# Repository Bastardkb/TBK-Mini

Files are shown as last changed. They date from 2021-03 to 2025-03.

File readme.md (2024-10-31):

# TBK Mini

A Dactyl Manuform Mini. Silent and compact, with per-key RGB.

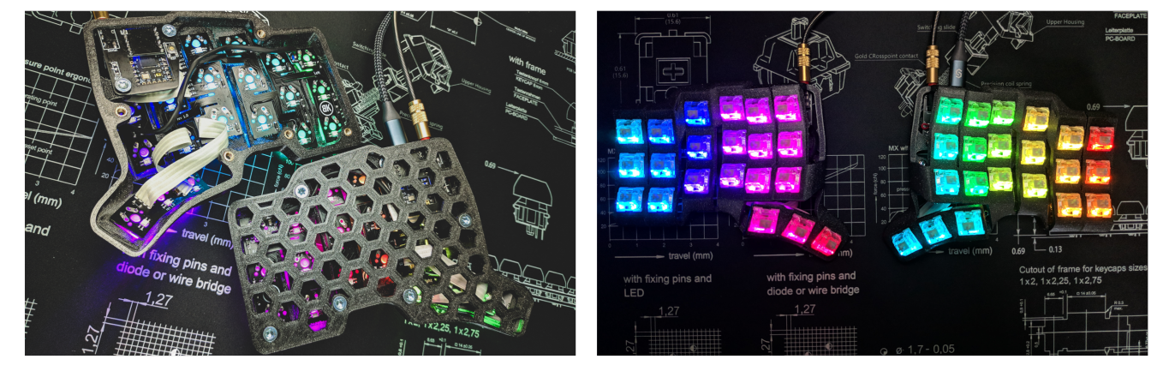
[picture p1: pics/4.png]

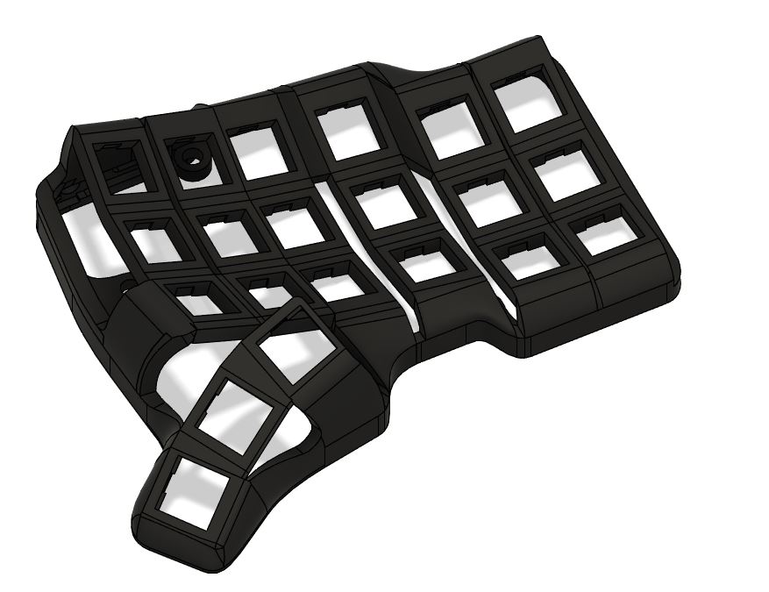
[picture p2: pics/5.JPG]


# Sourcing the components

## Electronic components

You will need to order the parts from a shop, and order some PCBs directly from the manufacturer.

Parts list:

| Part name | Amount | Link |
| --- | --- | --- |
| Flexible PCB for the plate | 2 | https://github.com/Bastardkb/TBK-Mini-PCB-plate |
| Flexible PCB for the thumbs | 2 | https://github.com/Bastardkb/TBK-Mini-PCB-thumb-cluster |
| Elite-C | 2 | |
| Elite-C adapter PCB V1.4 | 2 | https://github.com/Bastardkb/Elite-C-holder |
| SOD123 Diodes | 42 | |
| Ribbon cables Flexstrip | 34 | Farnell, Aliexpress |
| M4 8mm Torx Screw | 14 | Conrad |
| M4 screw insert, M4 X D6.0 X L5.0 | 14 | https://fr.aliexpress.com/item/4000232925592.html?spm=a2g0s.12269583.0.0.6aef4f282LZO4v |
| Audio jack, SMD | 2 | |
| Button, 4x4x1.5 | 2 | https://www.aliexpress.com/item/1005001304569553.html?spm=a2g0s.9042311.0.0.27424c4dDwgcp7 |

If you want RGB, you will also need:

| Part name | Amount | Format |
| --- | --- | --- |
| SK6812 Mini-E LEDs | 42 | |
| Capacitor, 1uF | 4 | 1206 |
| Resistor, 330Ohms | 4 | 1206 |
| Wires | | 28 AWG recommended, Black, Red, Color |
| Ribbon cables Flexstrip | 6 | |

## Print the case

The STL files are included in this Github repository.

Please find detailed instructions on how to print the case on the online instructions linked below.

There are optional tents, use the same ones as for the [Charybdis Mini 3x6](https://github.com/bastardkb/charybdis).

## Get a kit from BastardKB

You can also get a full Kit, including case and all PCBs and electronics required on the shop:
https://bastardkb.com/

If you want to print the case yourself, you can also get just the electronics Kit.

# Build guide

You can find detailed instruction on the online documentation linked below. For the TBK Mini, please follow the Skeletyl guide.

# Finding help

- Discord: https://bastardkb.com/discord
- Website: https://bastardkb.com/
- Docs: https://docs.bastardkb.com

# Forks

- [With loligagger holder for nice!nanos](https://github.com/nathanielks/TBK-Mini) - reset switch and power switch

# License

This work is licensed under a Creative Commons Attribution-NonCommercial-ShareAlike 4.0 International License.

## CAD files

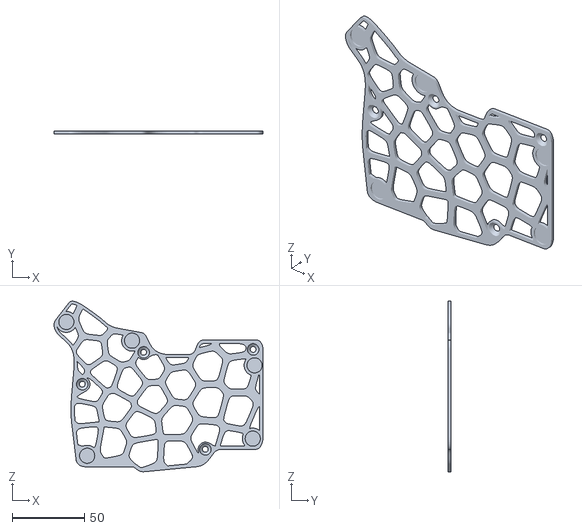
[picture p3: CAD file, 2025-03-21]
files/plate_flush_v1_v2.stl
144.4 x 2.00 x 117.9

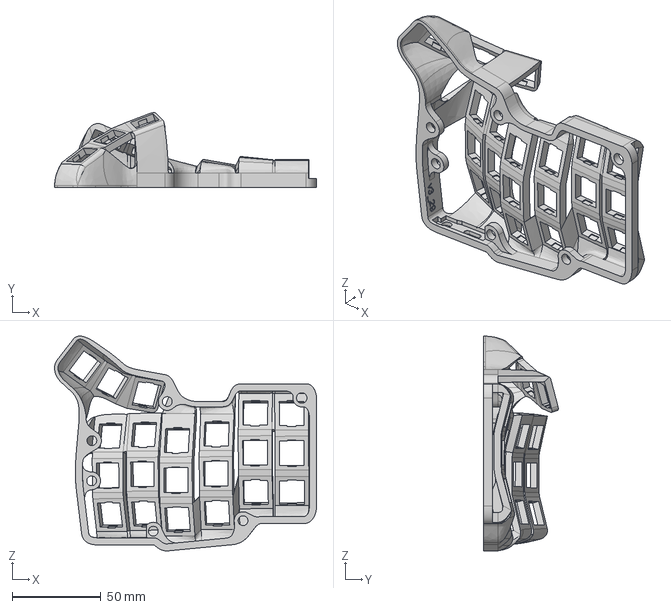
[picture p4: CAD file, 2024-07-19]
files/mini_v3 v29.step
147.4 x 42.0 x 120.9 mm

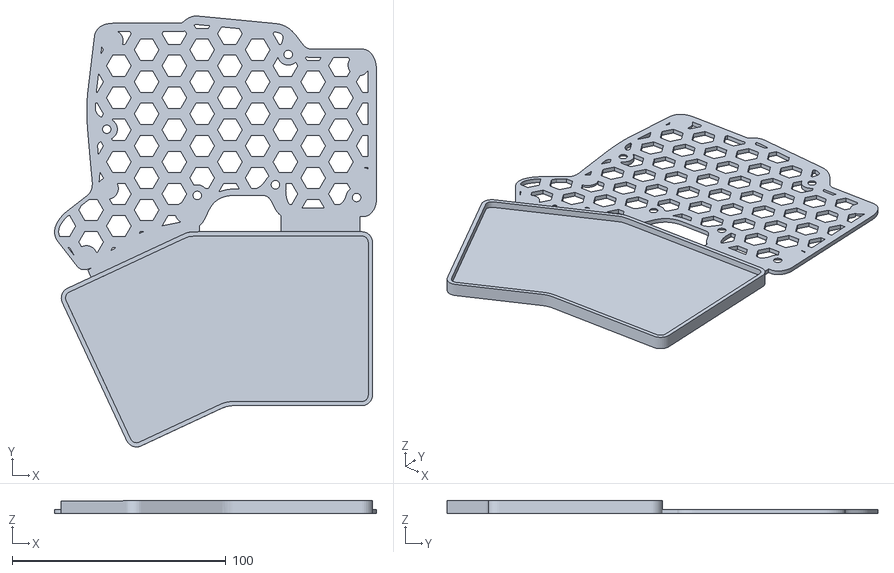
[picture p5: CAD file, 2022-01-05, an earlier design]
files/archive/plate_ergodox_ez_wing.stl
150.8 x 201.8 x 6.18

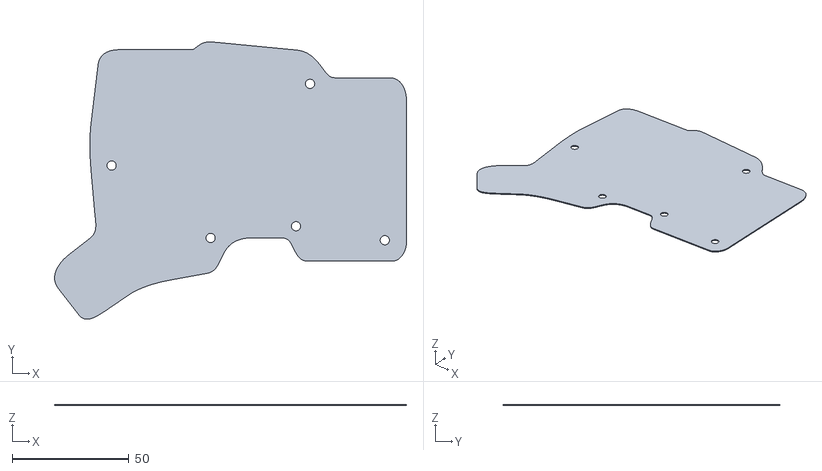
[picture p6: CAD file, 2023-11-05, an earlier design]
files/archive/tents/plate_protection_layer.stl
150.8 x 118.8 x 0.5

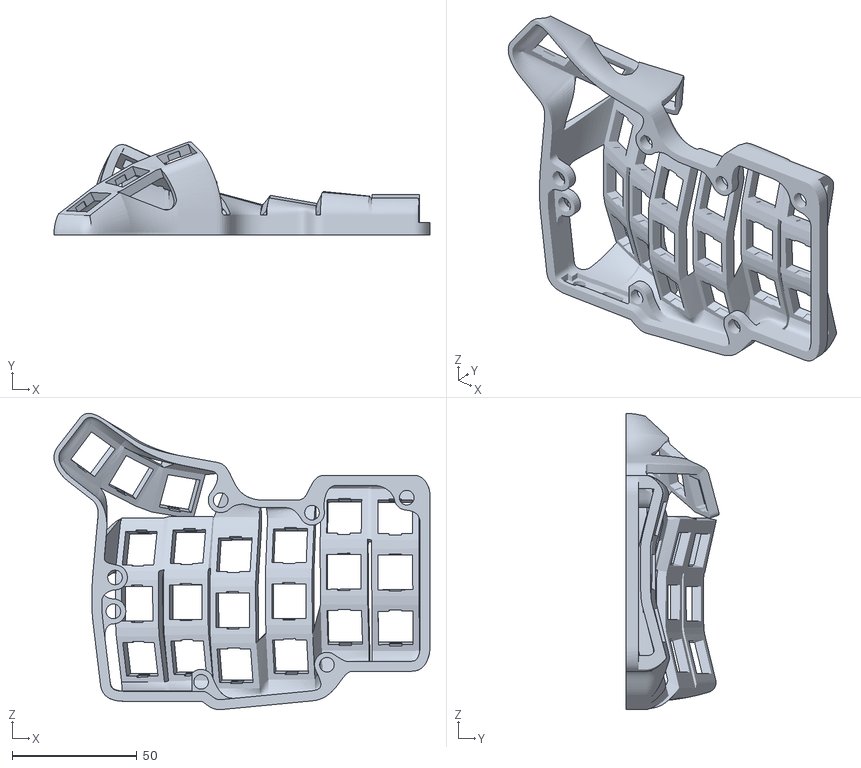
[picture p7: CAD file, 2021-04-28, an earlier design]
files/archive/case_v2_v88.stl
150.8 x 37.3 x 118.8

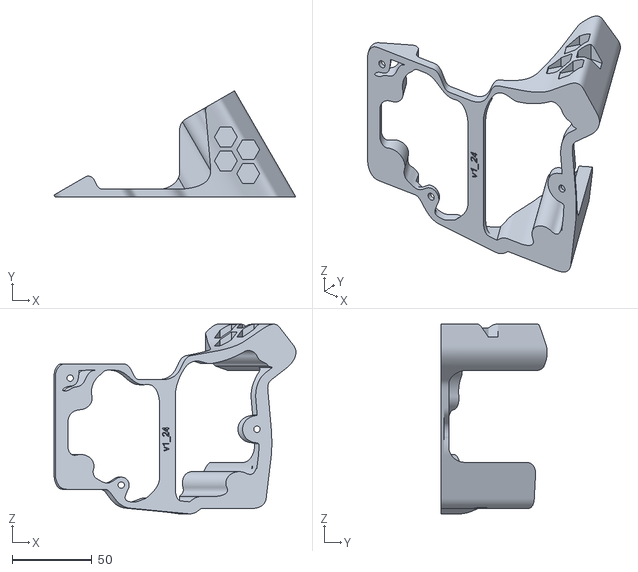
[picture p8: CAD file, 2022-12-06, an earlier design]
files/archive/tents/alient_tent_v1_24.stl
151.6 x 66.7 x 118.8

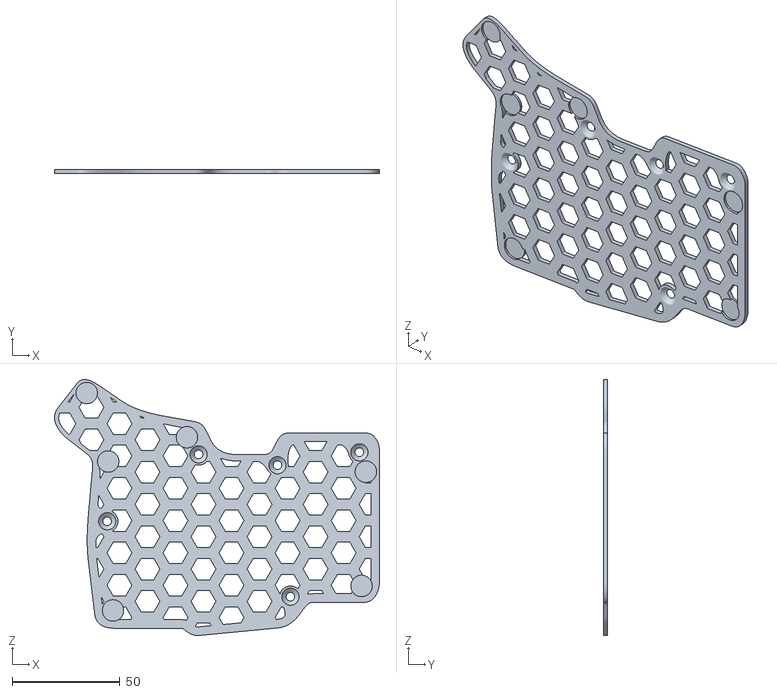
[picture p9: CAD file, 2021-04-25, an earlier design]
files/archive/plate_v2_v88.stl
150.8 x 2.00 x 118.8

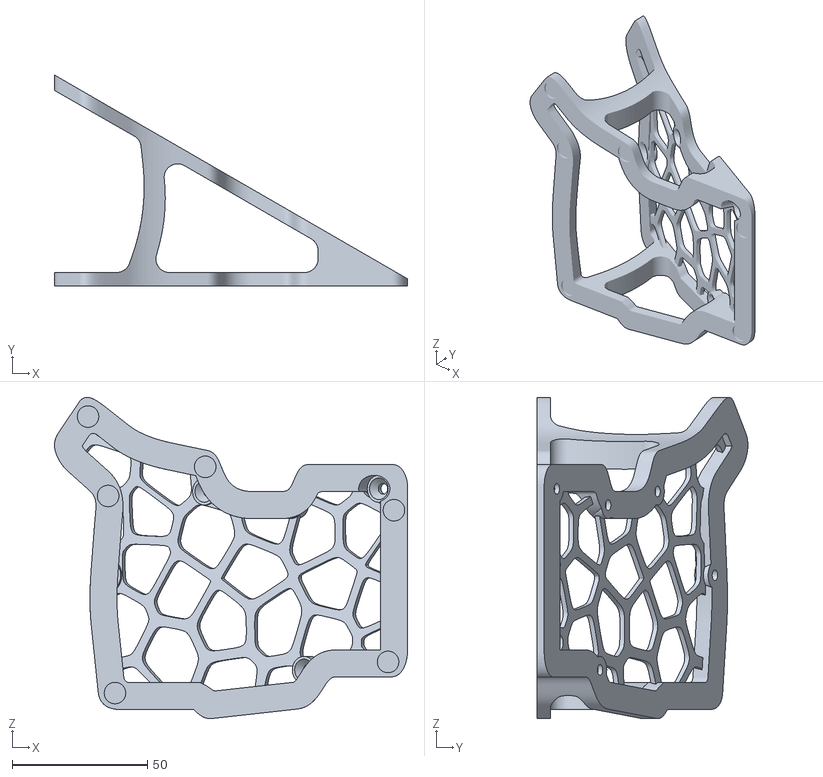
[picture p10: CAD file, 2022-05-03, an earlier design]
files/archive/tents/Organic Tent 30deg TBK-Mini 3x6.stl
130.6 x 78.0 x 118.8

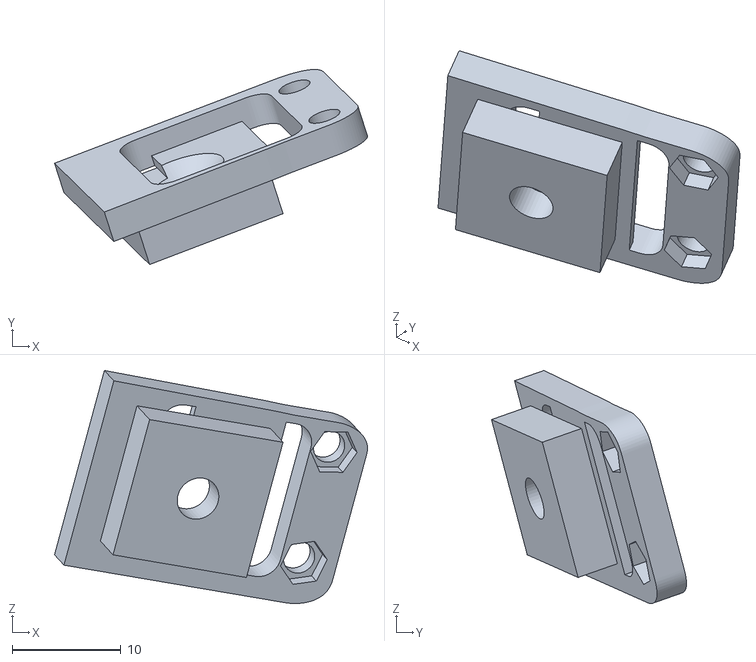
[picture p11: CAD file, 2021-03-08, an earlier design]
files/archive/adapter_v2_v75.stl
28.8 x 17.9 x 21.4

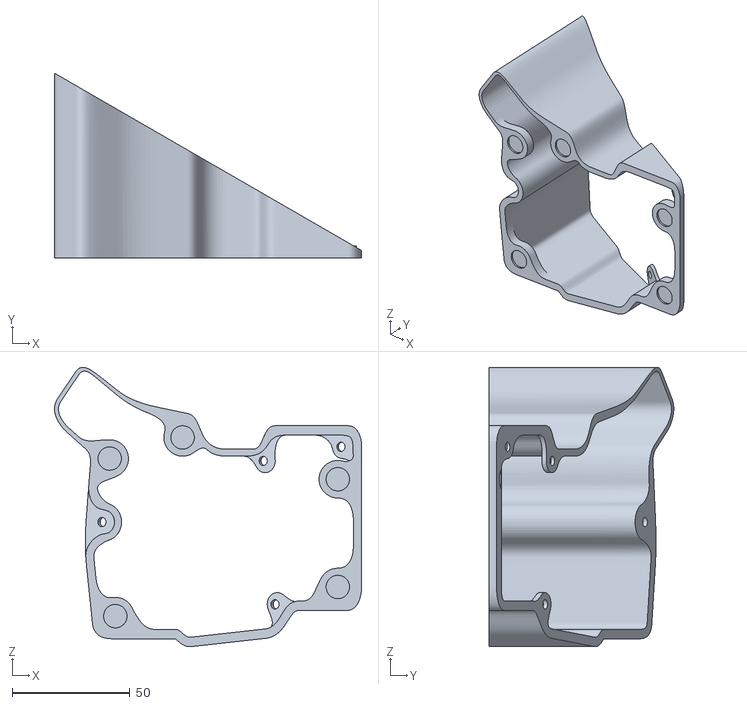
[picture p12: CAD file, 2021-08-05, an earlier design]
files/archive/tents/tent_30deg_v16.stl
130.6 x 78.5 x 118.8

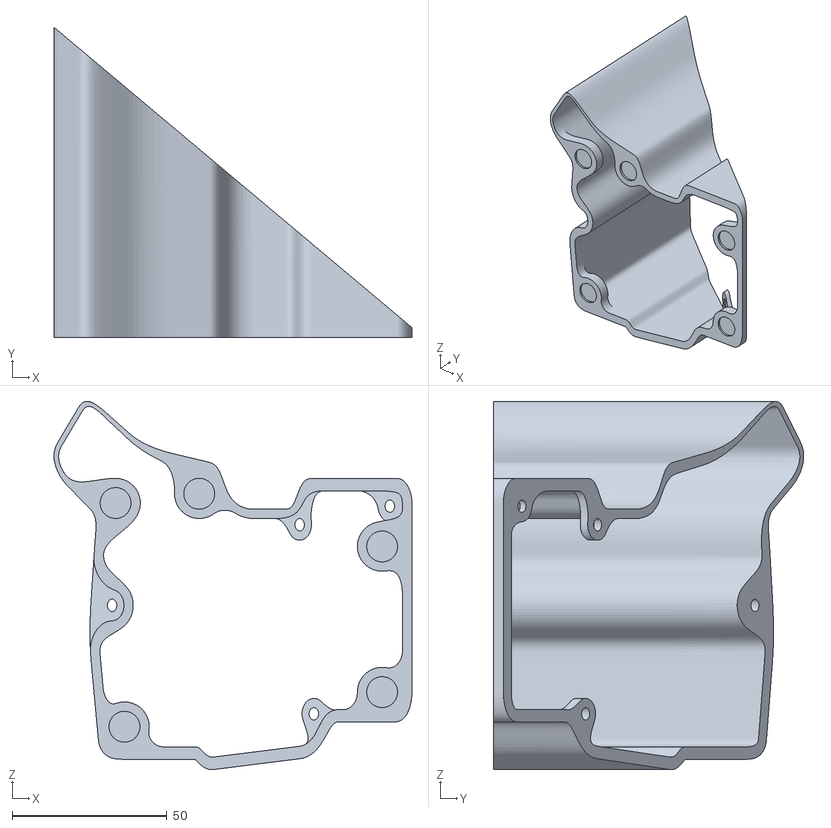
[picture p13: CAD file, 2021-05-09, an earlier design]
files/archive/tents/tent_40deg.stl
115.5 x 100.2 x 118.8

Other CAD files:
files/case_v3_v29.stl

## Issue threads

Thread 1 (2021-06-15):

Parametrization

hasufell, 2021-06-15:
This build doesn't seem to have a way to adjust it to different finger length or to add more rows like other Dactyl builds do.

How were the stl files generated?

bstiq, 2021-06-15:
Hi, thank you for getting in touch!

The keyboard was made entirely in Fusion 360, so it's not parametric.

It's a loss, but it also enabled me to tweak the design exactly how I
wanted. There's a lot of features that just wouldn't be possible (or very
hard) with clojure.

If you're interested, the fusion archive files are on the GitHub page.
There's also a 5x3 version, and I'm thinking of open sourcing the 6x4
version.

I also made a few video tutorials on YouTube on how to design a dactyl-like
keyboard in Fusion, if you want to go further.

Regards,
Quentin/Bastardkb

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

Closed 2021-07-12.

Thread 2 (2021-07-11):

4x5 build?

hasufell, 2021-07-11:
I bought the tbk mini electronics kit and am gonna build one.

However, I'm wondering if it's worthwhile to experiment with a 4x5 build that omits the outermost left column and adds one more row.

Is it difficult to prototype such a build?

bstiq, 2021-07-12:
Hello,

You can check some tips on how to design keyboards here:
https://www.youtube.com/watch?v=aYKJnKiDjNk

The point of those small keyboards is to move the hands as little as
possible though, so having 4 rows doesn't really make sense.

Regards,

*Quentin LEBASTARD*

Le dim. 11 juil. 2021 à 09:43, Julian Ospald ***@***.***> a
écrit :

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

hasufell, 2021-07-12:
> The point of those small keyboards is to move the hands as little as
possible though, so having 4 rows doesn't really make sense.

The kinesis has 4 and a half rows. Due to the strong curvature, I can reach all keys without lifting my wrist, EXCEPT the outermost column. I believe it's the main culprit for index finger strain: it's lateral movement, which is considered one of the worst penalties in many keyboard layout analyzers (workman layout was explicitly designed to remove lateral movement). I always bend my wrist sideways to reach this column, because stretching my index finger is much worse.

bstiq, 2021-07-12:
If you have issues with strain, going with 5 columns might be worth it.

When you say `EXCEPT the outermost index finger column`, what do you mean ? The pinky ? Or the top key on the index finger column ?

Here's some things to look into:
- alternative layouts like miryoku, dvorak, colemak
- if you're keen on going with 5 cols/4 rows, take a look at https://dactyl.siskam.link/ which can generate the kind of keyboard you're looking for.

Unfortunately at the moment I don't have any plans for a 5 cols x 4 rows keyboard.

Regards,

hasufell, 2021-07-12:
> When you say EXCEPT the outermost index finger column, what do you mean ? The pinky ? Or the top key on the index finger column ?

https://imgur.com/a/GZzgUgl

> alternative layouts like miryoku, dvorak, colemak

Yes, I use workman: https://workmanlayout.org/

bstiq, 2021-07-12:
So this column with the workman layout on right hand would be used for:
J, Y, K

It's also used on other layouts.
So if you want to omit this column you will need to make a new keymap.
Since it can be done in software it's more a soft issue first rather than
hard.
You could just disable this most inner column in code and work through
code, and see if it works for you.

And then after that, try to make a dacman. But this is the first time I
hear about this / index strain. Might be worth it testing other staggers /
tents to see if it relieves strain.

Regards,

*Quentin LEBASTARD*

Le lun. 12 juil. 2021 à 16:38, Julian Ospald ***@***.***> a
écrit :

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

hasufell, 2021-07-12:
> And then after that, try to make a dacman. But this is the first time I
hear about this / index strain. Might be worth it testing other staggers /
tents to see if it relieves strain.

Yes, I'm suffering from rheumatism, which affects the index fingers first. I've built a complete Lagrange, which was an awesome experience btw https://github.com/dpapavas/lagrange-keyboard/discussions/10

However, I feel the 35 degrees tenting angle has some unexpected side effects: when your hands are in handshake position, you're less likely to move your wrist upwards, so that your index finger is on the J, Y, K column. As a result, you're stretching your index finger up. It must have something to do with how the forearm muscles work. Overall, I prefer the tenting, because it relieves stress in your forearm, but I can't manage the index finger strain it causes.

> So if you want to omit this column you will need to make a new keymap.

There exists a keymap that's predestined for this purpose https://github.com/binarybottle/engram

The columns in question are not letters and so can easily be moved into a different layer or some other mechanism. However, in order for this to be remotely feasibly, I definitely would need another top row.

bstiq, 2021-07-13:
Hey,

The dactyl generator (https://dactyl.siskam.link/manuform) has an option for that (Inner Index Finger's Column).

At this point your best bet is to generate the dactyl through the website and find someone to print it / print it yourself.

Regards,

bstiq, 2021-08-15:
No update, closing

Closed 2021-08-15.

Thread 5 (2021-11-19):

Printing issues (leg broke)

hasufell, 2021-11-19:
Hi,

I've printed my first TBK Mini case (PETG white, 255 degrees celsius, settings pretty much per the build guide otherwise) and during removal of the support, a leg broke:
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

Is the model just fragile or is this because of print settings? Should I print it lying flat instead of upright? I'm assuming that will at least make the "legs" stronger, although you might see more layering on the outside of the case.

cfarvidson, 2021-11-19:
I've printed a few TBK minis and have printed them all laying flat.

I have never had an issue with anything breaking.

Here is my handwired build log: https://carl-fredrik.arvidson.io/posts/tbk-mini

hasufell, 2021-11-19:
> I have never had an issue with anything breaking.

Cool. Have you used the board for a while? How is the stability?

I've read that prints are weaker in Z-direction and when you type, the pressure on the keys pushes downwards in the Z-direction: https://www.hubs.com/knowledge-base/how-does-part-orientation-affect-3d-print/

bstiq, 2021-11-19:
Hello,

The case should be printed flat yes. Also check out the print advice here:
https://docs.bastardkb.com/hc/en-us/articles/360020031180-Print-settings-for-Dactyls

I've had no issues with stability and strength so far on my Skeletyl and
Charybdis Nano. I did make a few revisions of those keyboards to test
different case shapes for better strength.

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

hasufell, 2021-11-19:
Thanks, I'll  try that... the support structures the slicer creates in the upright position is also insane.

Closed 2021-11-19.

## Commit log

2021-03-08 add adapter
    [adapter_v2_v75.stl]
2021-03-24 add recess for pads
    [plate_v2_v58.stl, plate_v2_v78.stl]
2021-04-08 bigger screw inserts
    [case_v2_v73.stl, case_v2_v80.stl]
2021-04-09 switch to adapter 1.4
    [case_v2_v80.stl, case_v2_v81.stl]
2021-04-09 fix other screw insert
    [case_v2_v81.stl, case_v2_v82.stl]
2021-04-09 fix usb c position
    [case_v2_v82.stl, case_v2_v823.stl]
2021-04-09 fix version
    [case_v2_v83.stl]
2021-04-25 add 30 deg tent
    [tent_30deg.stl]
2021-04-25 add recess in plate for the anti-slip pads
    [plate_v2_v78.stl, plate_v2_v88.stl]
2021-04-28 more space for shield pcb screw
    [case_v2_v83.stl, case_v2_v88.stl]
2021-05-09 add 40de tent
    [tent_40deg.stl]
2021-08-05 fix screw hole orientation
    [tent_30deg.stl, tent_30deg_v16.stl]
2021-08-05 add missing anti slip pad holes
    [tent_30deg_v16.stl]
2022-01-04 Adds the ergodox ez wrist rest plate
    [plate_ergodox_ez_wing.stl]
2022-05-03 added 30 degree organic tent
    Matches the [organic tent for the 3x6 Charybdis](https://github.com/Bastardkb/Charybdis/pull/11)
    [Organic Tent 30deg TBK-Mini 3x6.stl]
2022-05-03 added folder for tents
    [Organic Tent 30deg TBK-Mini 3x6.stl, tent_30deg_v16.stl, tent_40deg.stl]
2023-02-16 Created plate protection layer for tents
    Created a plate protection layer to guarantee more exposed bottom surface in tent design
    [plate_protection_layer.stl]
2023-02-16 Added documentation and put the model in the right folder
    - Added a line to the Readme file to explain the use case of the new model
    - Moved the model to the `tent` folder
    [plate_protection_layer.stl]
2023-08-14 uploead v3
    [Organic Tent 30deg TBK-Mini 3x6.stl, adapter_v2_v75.stl, alient_tent_v1_24.stl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]
2024-07-19 add plate and step case
    [mini_v3 v29.step, plate.dxf]
2025-03-21 flush plate
    [plate.dxf, plate_flush_v1_v2.stl, plate_v3_v29.dxf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]
